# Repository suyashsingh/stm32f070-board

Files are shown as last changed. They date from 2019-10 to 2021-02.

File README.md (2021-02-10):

# Hardware Board Design for STM32F070F6
`STM32F070F6` is a 32-bit ARM Cortex-M0 microcontroller from ST. This repository contains the hardware files needed for creating a basic board for working with this micro controller. 

EDA Tool: **KiCad(5.0.1)**.

**Many thanks to [Balram](https://www.linkedin.com/in/balram-jatav/) for helping me out with the PCB design :slightly_smiling_face:**

## Images 
1. Real Board - before assembly
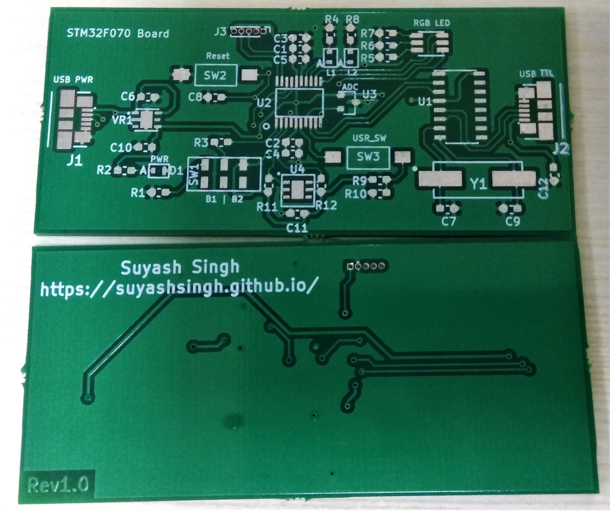
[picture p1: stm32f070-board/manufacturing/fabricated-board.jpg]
board-fab


2. 3D View of the Board
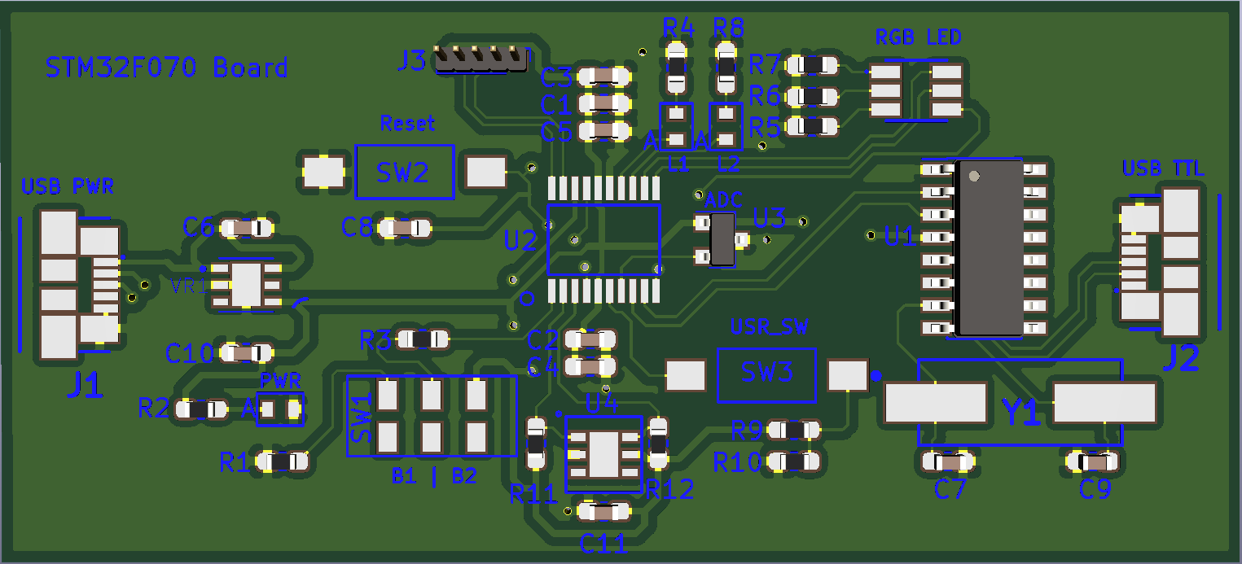
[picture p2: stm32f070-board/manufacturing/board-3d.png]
board-3d


3. Fab House Front Copper Layer
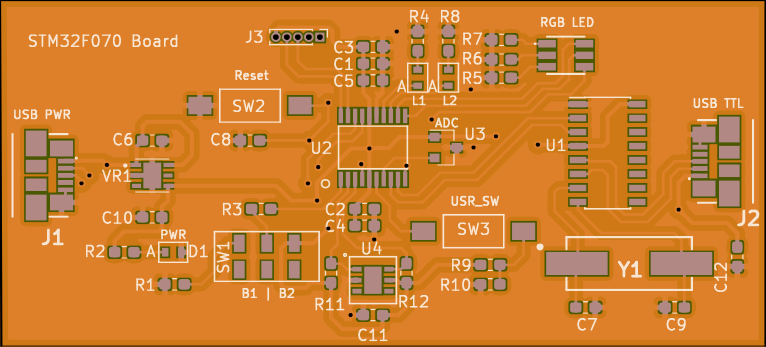
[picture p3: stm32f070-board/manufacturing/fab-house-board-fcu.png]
board-fcu


4. Board Front Copper Layer
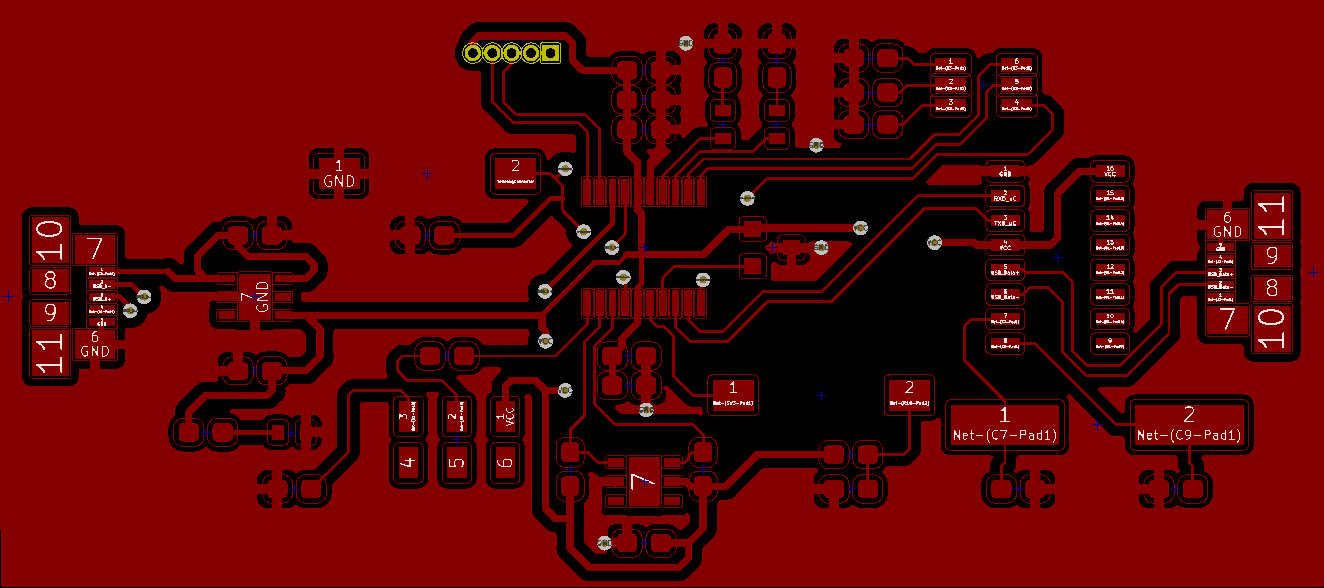
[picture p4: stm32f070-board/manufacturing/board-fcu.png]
board-fcu


## Board Bring Up Checklist
- [x] 1. Change trace width of power tracks
- [x] 2. Merge `dev` branch to master
- [x] 3. Export gerbers - research about fab houses
- [x] 4. Verify gerbers
- [x] 5. Send board to fab house
- [x] 6. Generate BOM
- [x] 7. Order component and tools

## Timeline
| Event | Date |
| --- | --- |
| Project Start | 12 Sep 2019 |
| Schematic Complete | 5th Oct 2019  |
| Layout Complete | 6th Oct 2019  |
| Sent gerbers for fabrication  | 3rd Dec 2019  |
| Received PCB's from fab house | 11th Dec 2019 |
| BOM Complete | 17th Dec 2019 |
| Ordered Components & Tools | 17th Dec 2019 |

## Notes
1. Changed the switches with were earlier decided from *robu.in* to [this](https://in.element14.com/alcoswitch-te-connectivity/fsmsm/switch-spst-0-05a-24vdc-smd/dp/1703878) from element14, as mechanical dimensions were not available.

2. Links that might be useful for usb connector:
	+ [Element 14 Page](https://in.element14.com/molex/47346-0001/usb-conn-2-0-micro-usb-type-b/dp/1568026?st=mirco%20usb%20connector)
	+ [Digi Key Kicad Library](https://github.com/Digi-Key/digikey-kicad-library/tree/master/) - Search for MPN
	+ [Mouser](https://www.mouser.in/ProductDetail/Molex/47346-0001?qs=c2CV6XM0DweJBWaSeyWeCw%3D%3D)

3. Always do a board check when you receive the board from the fab house. You can do:
	
	a. Visual Inspection
	
	b. Check for short between the power rails - This board has 3V3 and 5V power rails. Thanks to Balram for pointing out this.

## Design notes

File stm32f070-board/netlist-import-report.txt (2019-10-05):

Info: Checking netlist symbol footprint “R2:/5D7A0C0E:Resistor_SMD:R_0603_1608Metric_Pad1.05x0.95mm_HandSolder”.

Info: Checking netlist symbol footprint “C9:/5D8B533C:Capacitor_SMD:C_0603_1608Metric_Pad1.05x0.95mm_HandSolder”.

Info: Checking netlist symbol footprint “U3:/5D8108A1:Package_TO_SOT_SMD:SOT-23”.

Info: Checking netlist symbol footprint “C10:/5D7A0CB9:Capacitor_SMD:C_0603_1608Metric_Pad1.05x0.95mm_HandSolder”.

Info: Checking netlist symbol footprint “C11:/5D8253F2:Capacitor_SMD:C_0603_1608Metric_Pad1.05x0.95mm_HandSolder”.

Info: Checking netlist symbol footprint “D1:/5D7A0C7B:stm32f070-board:LED_VISHAY”.

Info: Checking netlist symbol footprint “D2:/5D7DA43F:stm32f070-board:LED_VISHAY”.

Info: Checking netlist symbol footprint “D3:/5D801829:stm32f070-board:PLCC6”.

Info: Checking netlist symbol footprint “U2:/5D7A7448:stm32f070-board:TSSOP20_P0.65mm”.

Info: Checking netlist symbol footprint “J1:/5D7A0AEB:stm32f070-board:usb”.

Info: Checking netlist symbol footprint “J2:/5D8A34F0:stm32f070-board:usb”.

Info: Checking netlist symbol footprint “J3:/5D7FD58A:Connector_PinHeader_1.00mm:PinHeader_1x05_P1.00mm_Vertical”.

Info: Checking netlist symbol footprint “U1:/5D88F99C:Package_SO:SOIC-16_3.9x9.9mm_P1.27mm”.

Info: Checking netlist symbol footprint “SW3:/5D8E3013:stm32f070-board:TACTILE_SWITCH_3.5X6.0mm”.

Info: Checking netlist symbol footprint “R1:/5D7D0CB6:Resistor_SMD:R_0603_1608Metric_Pad1.05x0.95mm_HandSolder”.

Info: Checking netlist symbol footprint “D4:/5D7D3C44:stm32f070-board:LED_VISHAY”.

Info: Checking netlist symbol footprint “SW2:/5D7AAB22:stm32f070-board:TACTILE_SWITCH_3.5X6.0mm”.

Info: Checking netlist symbol footprint “R3:/5D7A777D:Resistor_SMD:R_0603_1608Metric_Pad1.05x0.95mm_HandSolder”.

Info: Checking netlist symbol footprint “SW1:/5D7BECF9:stm32f070-board:SLIDE_SWITCH_3.6x9.0mm”.

Info: Checking netlist symbol footprint “R4:/5D7E3D28:Resistor_SMD:R_0603_1608Metric_Pad1.05x0.95mm_HandSolder”.

Info: Checking netlist symbol footprint “R5:/5D7D84F8:Resistor_SMD:R_0603_1608Metric_Pad1.05x0.95mm_HandSolder”.

Info: Checking netlist symbol footprint “R12:/5D82F9A1:Resistor_SMD:R_0603_1608Metric_Pad1.05x0.95mm_HandSolder”.

Info: Checking netlist symbol footprint “C1:/5D7AE4EA:Capacitor_SMD:C_0603_1608Metric_Pad1.05x0.95mm_HandSolder”.

Info: Checking netlist symbol footprint “R6:/5D7D84B2:Resistor_SMD:R_0603_1608Metric_Pad1.05x0.95mm_HandSolder”.

Info: Checking netlist symbol footprint “R11:/5D82FB6B:Resistor_SMD:R_0603_1608Metric_Pad1.05x0.95mm_HandSolder”.

Info: Checking netlist symbol footprint “R7:/5D7D845C:Resistor_SMD:R_0603_1608Metric_Pad1.05x0.95mm_HandSolder”.

Info: Checking netlist symbol footprint “R8:/5D7D3F06:Resistor_SMD:R_0603_1608Metric_Pad1.05x0.95mm_HandSolder”.

Info: Checking netlist symbol footprint “R10:/5D7B88B1:Resistor_SMD:R_0603_1608Metric_Pad1.05x0.95mm_HandSolder”.

Info: Checking netlist symbol footprint “R9:/5D7CB083:Resistor_SMD:R_0603_1608Metric_Pad1.05x0.95mm_HandSolder”.

Info: Checking netlist symbol footprint “C4:/5D7B4E86:Capacitor_SMD:C_0603_1608Metric_Pad1.05x0.95mm_HandSolder”.

Info: Checking netlist symbol footprint “VR1:/5D7A09D8:stm32f070-board:voltage-reg”.

Info: Checking netlist symbol footprint “C7:/5D8B4EE6:Capacitor_SMD:C_0603_1608Metric_Pad1.05x0.95mm_HandSolder”.

Info: Checking netlist symbol footprint “C5:/5D7AE616:Capacitor_SMD:C_0603_1608Metric_Pad1.05x0.95mm_HandSolder”.

Info: Checking netlist symbol footprint “C6:/5D7A0BBE:Capacitor_SMD:C_0603_1608Metric_Pad1.05x0.95mm_HandSolder”.

Info: Checking netlist symbol footprint “Y1:/5D8B4C70:stm32f070-board:HC_49US-(AT49)_1”.

Info: Checking netlist symbol footprint “C2:/5D7B4ED0:Capacitor_SMD:C_0603_1608Metric_Pad1.05x0.95mm_HandSolder”.

Info: Checking netlist symbol footprint “C3:/5D7AE5E0:Capacitor_SMD:C_0603_1608Metric_Pad1.05x0.95mm_HandSolder”.

Info: Checking netlist symbol footprint “U4:/5D81A91E:stm32f070-board:Si705x_Footprint_P1.0mm”.

Info: Checking netlist symbol footprint “C8:/5D7AACAA:Capacitor_SMD:C_0603_1608Metric_Pad1.05x0.95mm_HandSolder”.

Adding new symbol “SW2:/5D7AAB22” footprint “stm32f070-board:TACTILE_SWITCH_3.5X6.0mm”.

Changing footprint “SW2:/5D7AAB22” pad “2” net name from “” to “/ToDebugConnector”.

Adding new symbol “VR1:/5D7A09D8” footprint “stm32f070-board:voltage-reg”.

Changing footprint “VR1:/5D7A09D8” pad “7” net name from “” to “GND”.

Changing footprint “SW1:/5D7BECF9” pad “3” net name from “” to “Net-(R1-Pad2)”.

Changing footprint “SW1:/5D7BECF9” pad “2” net name from “” to “Net-(R3-Pad2)”.

Adding new symbol “SW3:/5D8E3013” footprint “stm32f070-board:TACTILE_SWITCH_3.5X6.0mm”.

Changing footprint “SW2:/5D7AAB22” pad “1” net name from “” to “GND”.

Changing footprint “VR1:/5D7A09D8” pad “4” net name from “” to “VCC”.

Changing footprint “SW3:/5D8E3013” pad “1” net name from “” to “Net-(SW3-Pad1)”.

Changing footprint “SW3:/5D8E3013” pad “2” net name from “” to “Net-(R10-Pad2)”.

Changing footprint “U4:/5D81A91E” pad “6” net name from “” to “/SCL”.

Adding new symbol “U1:/5D88F99C” footprint “Package_SO:SOIC-16_3.9x9.9mm_P1.27mm”.

Changing footprint “U4:/5D81A91E” pad “5” net name from “” to “VCC”.

Changing footprint “U1:/5D88F99C” pad “1” net name from “” to “GND”.

Changing footprint “U1:/5D88F99C” pad “2” net name from “” to “/RXD_uC”.

Changing footprint “U1:/5D88F99C” pad “3” net name from “” to “/TXD_uC”.

Changing footprint “VR1:/5D7A09D8” pad “1” net name from “” to “Net-(C6-Pad1)”.

Changing footprint “Y1:/5D8B4C70” pad “2” net name from “” to “Net-(C9-Pad1)”.

Changing footprint “R9:/5D7CB083” pad “2” net name from “” to “VCC”.

Changing footprint “R9:/5D7CB083” pad “1” net name from “” to “Net-(R10-Pad2)”.

Changing footprint “Y1:/5D8B4C70” pad “1” net name from “” to “Net-(C7-Pad1)”.

Adding new symbol “Y1:/5D8B4C70” footprint “stm32f070-board:HC_49US-(AT49)_1”.

Adding new symbol “R10:/5D7B88B1” footprint “Resistor_SMD:R_0603_1608Metric_Pad1.05x0.95mm_HandSolder”.

Changing footprint “R10:/5D7B88B1” pad “1” net name from “” to “GND”.

Changing footprint “R10:/5D7B88B1” pad “2” net name from “” to “Net-(R10-Pad2)”.

Adding new symbol “R11:/5D82FB6B” footprint “Resistor_SMD:R_0603_1608Metric_Pad1.05x0.95mm_HandSolder”.

Changing footprint “R11:/5D82FB6B” pad “2” net name from “” to “/SDA”.

Changing footprint “SW1:/5D7BECF9” pad “1” net name from “” to “VCC”.

Changing footprint “VR1:/5D7A09D8” pad “2” net name from “” to “GND”.

Changing footprint “R11:/5D82FB6B” pad “1” net name from “” to “VCC”.

Changing footprint “VR1:/5D7A09D8” pad “3” net name from “” to “Net-(VR1-Pad3)”.

Adding new symbol “R12:/5D82F9A1” footprint “Resistor_SMD:R_0603_1608Metric_Pad1.05x0.95mm_HandSolder”.

Changing footprint “R12:/5D82F9A1” pad “1” net name from “” to “VCC”.

Changing footprint “R12:/5D82F9A1” pad “2” net name from “” to “/SCL”.

Changing footprint “U1:/5D88F99C” pad “6” net name from “” to “Net-(J2-Pad2)”.

Changing footprint “VR1:/5D7A09D8” pad “6” net name from “” to “Net-(C6-Pad1)”.

Adding new symbol “SW1:/5D7BECF9” footprint “stm32f070-board:SLIDE_SWITCH_3.6x9.0mm”.

Changing footprint “U2:/5D7A7448” pad “17” net name from “” to “/USB_DM”.

Changing footprint “U2:/5D7A7448” pad “6” net name from “” to “Net-(SW3-Pad1)”.

Changing footprint “U4:/5D81A91E” pad “2” net name from “” to “GND”.

Changing footprint “U2:/5D7A7448” pad “7” net name from “” to “/ADC”.

Changing footprint “U2:/5D7A7448” pad “8” net name from “” to “/TXD_uC”.

Changing footprint “U2:/5D7A7448” pad “9” net name from “” to “/RXD_uC”.

Changing footprint “U4:/5D81A91E” pad “1” net name from “” to “/SDA”.

Changing footprint “U2:/5D7A7448” pad “10” net name from “” to “Net-(D3-Pad4)”.

Changing footprint “U2:/5D7A7448” pad “20” net name from “” to “/PA20”.

Changing footprint “U2:/5D7A7448” pad “19” net name from “” to “/PA19”.

Changing footprint “U2:/5D7A7448” pad “18” net name from “” to “/USB_DP”.

Changing footprint “U2:/5D7A7448” pad “5” net name from “” to “VCC”.

Changing footprint “U2:/5D7A7448” pad “16” net name from “” to “VCC”.

Adding new symbol “U4:/5D81A91E” footprint “stm32f070-board:Si705x_Footprint_P1.0mm”.

Changing footprint “U2:/5D7A7448” pad “15” net name from “” to “GND”.

Changing footprint “U2:/5D7A7448” pad “14” net name from “” to “Net-(D2-Pad2)”.

Changing footprint “U2:/5D7A7448” pad “13” net name from “” to “Net-(D4-Pad2)”.

Changing footprint “U2:/5D7A7448” pad “12” net name from “” to “Net-(D3-Pad6)”.

Changing footprint “U2:/5D7A7448” pad “11” net name from “” to “Net-(D3-Pad5)”.

Changing footprint “U3:/5D8108A1” pad “3” net name from “” to “GND”.

Adding new symbol “U3:/5D8108A1” footprint “Package_TO_SOT_SMD:SOT-23”.

Changing footprint “U3:/5D8108A1” pad “1” net name from “” to “VCC”.

Changing footprint “U1:/5D88F99C” pad “14” net name from “” to “Net-(U1-Pad14)”.

Changing footprint “U1:/5D88F99C” pad “5” net name from “” to “Net-(J2-Pad3)”.

Changing footprint “U3:/5D8108A1” pad “2” net name from “” to “/ADC”.

Changing footprint “U1:/5D88F99C” pad “7” net name from “” to “Net-(C7-Pad1)”.

Changing footprint “U4:/5D81A91E” pad “4” net name from “” to “Net-(U4-Pad4)”.

Changing footprint “U1:/5D88F99C” pad “8” net name from “” to “Net-(C9-Pad1)”.

Changing footprint “U1:/5D88F99C” pad “9” net name from “” to “Net-(U1-Pad9)”.

Changing footprint “U1:/5D88F99C” pad “10” net name from “” to “Net-(U1-Pad10)”.

Changing footprint “U1:/5D88F99C” pad “11” net name from “” to “Net-(U1-Pad11)”.

Changing footprint “U1:/5D88F99C” pad “12” net name from “” to “Net-(U1-Pad12)”.

Changing footprint “U1:/5D88F99C” pad “13” net name from “” to “Net-(U1-Pad13)”.

Changing footprint “U1:/5D88F99C” pad “4” net name from “” to “VCC”.

Changing footprint “U1:/5D88F99C” pad “15” net name from “” to “Net-(U1-Pad15)”.

Changing footprint “U1:/5D88F99C” pad “16” net name from “” to “VCC”.

Changing footprint “U4:/5D81A91E” pad “3” net name from “” to “Net-(U4-Pad3)”.

Changing footprint “R5:/5D7D84F8” pad “1” net name from “” to “Net-(D3-Pad3)”.

Adding new symbol “U2:/5D7A7448” footprint “stm32f070-board:TSSOP20_P0.65mm”.

Changing footprint “U2:/5D7A7448” pad “1” net name from “” to “Net-(R3-Pad1)”.

Changing footprint “U2:/5D7A7448” pad “2” net name from “” to “/SDA”.

Changing footprint “U2:/5D7A7448” pad “3” net name from “” to “/SCL”.

Changing footprint “U2:/5D7A7448” pad “4” net name from “” to “/ToDebugConnector”.

Changing footprint “D1:/5D7A0C7B” pad “2” net name from “” to “Net-(D1-Pad2)”.

Changing footprint “C8:/5D7AACAA” pad “1” net name from “” to “/ToDebugConnector”.

Adding new symbol “C9:/5D8B533C” footprint “Capacitor_SMD:C_0603_1608Metric_Pad1.05x0.95mm_HandSolder”.

Changing footprint “C9:/5D8B533C” pad “1” net name from “” to “Net-(C9-Pad1)”.

Changing footprint “C9:/5D8B533C” pad “2” net name from “” to “GND”.

Adding new symbol “C10:/5D7A0CB9” footprint “Capacitor_SMD:C_0603_1608Metric_Pad1.05x0.95mm_HandSolder”.

Changing footprint “C10:/5D7A0CB9” pad “2” net name from “” to “GND”.

Changing footprint “C10:/5D7A0CB9” pad “1” net name from “” to “VCC”.

Adding new symbol “C11:/5D8253F2” footprint “Capacitor_SMD:C_0603_1608Metric_Pad1.05x0.95mm_HandSolder”.

Changing footprint “C11:/5D8253F2” pad “1” net name from “” to “GND”.

Changing footprint “C11:/5D8253F2” pad “2” net name from “” to “VCC”.

Adding new symbol “D1:/5D7A0C7B” footprint “stm32f070-board:LED_VISHAY”.

Changing footprint “C8:/5D7AACAA” pad “2” net name from “” to “GND”.

Changing footprint “D1:/5D7A0C7B” pad “1” net name from “” to “GND”.

Adding new symbol “D2:/5D7DA43F” footprint “stm32f070-board:LED_VISHAY”.

Changing footprint “D2:/5D7DA43F” pad “1” net name from “” to “Net-(D2-Pad1)”.

Changing footprint “D2:/5D7DA43F” pad “2” net name from “” to “Net-(D2-Pad2)”.

Adding new symbol “D3:/5D801829” footprint “stm32f070-board:PLCC6”.

Changing footprint “D3:/5D801829” pad “1” net name from “” to “Net-(D3-Pad1)”.

Changing footprint “D3:/5D801829” pad “2” net name from “” to “Net-(D3-Pad2)”.

Changing footprint “D3:/5D801829” pad “3” net name from “” to “Net-(D3-Pad3)”.

Changing footprint “D3:/5D801829” pad “4” net name from “” to “Net-(D3-Pad4)”.

Changing footprint “D3:/5D801829” pad “5” net name from “” to “Net-(D3-Pad5)”.

Changing footprint “D3:/5D801829” pad “6” net name from “” to “Net-(D3-Pad6)”.

Changing footprint “C4:/5D7B4E86” pad “1” net name from “” to “VCC”.

Adding new symbol “C1:/5D7AE4EA” footprint “Capacitor_SMD:C_0603_1608Metric_Pad1.05x0.95mm_HandSolder”.

Changing footprint “C1:/5D7AE4EA” pad “1” net name from “” to “VCC”.

Changing footprint “C1:/5D7AE4EA” pad “2” net name from “” to “GND”.

Adding new symbol “C2:/5D7B4ED0” footprint “Capacitor_SMD:C_0603_1608Metric_Pad1.05x0.95mm_HandSolder”.

Changing footprint “C2:/5D7B4ED0” pad “1” net name from “” to “VCC”.

Changing footprint “C2:/5D7B4ED0” pad “2” net name from “” to “GND”.

Adding new symbol “C3:/5D7AE5E0” footprint “Capacitor_SMD:C_0603_1608Metric_Pad1.05x0.95mm_HandSolder”.

Changing footprint “C3:/5D7AE5E0” pad “2” net name from “” to “GND”.

Changing footprint “C3:/5D7AE5E0” pad “1” net name from “” to “VCC”.

Adding new symbol “C4:/5D7B4E86” footprint “Capacitor_SMD:C_0603_1608Metric_Pad1.05x0.95mm_HandSolder”.

Changing footprint “C4:/5D7B4E86” pad “2” net name from “” to “GND”.

Adding new symbol “D4:/5D7D3C44” footprint “stm32f070-board:LED_VISHAY”.

Adding new symbol “C5:/5D7AE616” footprint “Capacitor_SMD:C_0603_1608Metric_Pad1.05x0.95mm_HandSolder”.

Changing footprint “C5:/5D7AE616” pad “1” net name from “” to “VCC”.

Changing footprint “C5:/5D7AE616” pad “2” net name from “” to “GND”.

Adding new symbol “C6:/5D7A0BBE” footprint “Capacitor_SMD:C_0603_1608Metric_Pad1.05x0.95mm_HandSolder”.

Changing footprint “C6:/5D7A0BBE” pad “1” net name from “” to “Net-(C6-Pad1)”.

Changing footprint “C6:/5D7A0BBE” pad “2” net name from “” to “GND”.

Adding new symbol “C7:/5D8B4EE6” footprint “Capacitor_SMD:C_0603_1608Metric_Pad1.05x0.95mm_HandSolder”.

Changing footprint “C7:/5D8B4EE6” pad “2” net name from “” to “GND”.

Changing footprint “C7:/5D8B4EE6” pad “1” net name from “” to “Net-(C7-Pad1)”.

Adding new symbol “C8:/5D7AACAA” footprint “Capacitor_SMD:C_0603_1608Metric_Pad1.05x0.95mm_HandSolder”.

Adding new symbol “R5:/5D7D84F8” footprint “Resistor_SMD:R_0603_1608Metric_Pad1.05x0.95mm_HandSolder”.

Changing footprint “R1:/5D7D0CB6” pad “2” net name from “” to “Net-(R1-Pad2)”.

Changing footprint “R1:/5D7D0CB6” pad “1” net name from “” to “GND”.

Adding new symbol “R2:/5D7A0C0E” footprint “Resistor_SMD:R_0603_1608Metric_Pad1.05x0.95mm_HandSolder”.

Changing footprint “R2:/5D7A0C0E” pad “1” net name from “” to “VCC”.

Changing footprint “R2:/5D7A0C0E” pad “2” net name from “” to “Net-(D1-Pad2)”.

Adding new symbol “R3:/5D7A777D” footprint “Resistor_SMD:R_0603_1608Metric_Pad1.05x0.95mm_HandSolder”.

Changing footprint “R3:/5D7A777D” pad “2” net name from “” to “Net-(R3-Pad2)”.

Changing footprint “R3:/5D7A777D” pad “1” net name from “” to “Net-(R3-Pad1)”.

Adding new symbol “R4:/5D7E3D28” footprint “Resistor_SMD:R_0603_1608Metric_Pad1.05x0.95mm_HandSolder”.

Changing footprint “R4:/5D7E3D28” pad “1” net name from “” to “Net-(D2-Pad1)”.

Changing footprint “R4:/5D7E3D28” pad “2” net name from “” to “GND”.

Adding new symbol “R1:/5D7D0CB6” footprint “Resistor_SMD:R_0603_1608Metric_Pad1.05x0.95mm_HandSolder”.

Changing footprint “R5:/5D7D84F8” pad “2” net name from “” to “GND”.

Adding new symbol “R6:/5D7D84B2” footprint “Resistor_SMD:R_0603_1608Metric_Pad1.05x0.95mm_HandSolder”.

Changing footprint “R6:/5D7D84B2” pad “1” net name from “” to “Net-(D3-Pad2)”.

Changing footprint “R6:/5D7D84B2” pad “2” net name from “” to “GND”.

Adding new symbol “R7:/5D7D845C” footprint “Resistor_SMD:R_0603_1608Metric_Pad1.05x0.95mm_HandSolder”.

Changing footprint “R7:/5D7D845C” pad “2” net name from “” to “GND”.

Changing footprint “R7:/5D7D845C” pad “1” net name from “” to “Net-(D3-Pad1)”.

Adding new symbol “R8:/5D7D3F06” footprint “Resistor_SMD:R_0603_1608Metric_Pad1.05x0.95mm_HandSolder”.

Changing footprint “R8:/5D7D3F06” pad “1” net name from “” to “Net-(D4-Pad1)”.

Changing footprint “R8:/5D7D3F06” pad “2” net name from “” to “GND”.

Changing footprint “J2:/5D8A34F0” pad “5” net name from “” to “GND”.

Changing footprint “D4:/5D7D3C44” pad “2” net name from “” to “Net-(D4-Pad2)”.

Changing footprint “D4:/5D7D3C44” pad “1” net name from “” to “Net-(D4-Pad1)”.

Adding new symbol “J1:/5D7A0AEB” footprint “stm32f070-board:usb”.

Changing footprint “J1:/5D7A0AEB” pad “1” net name from “” to “Net-(C6-Pad1)”.

Changing footprint “J1:/5D7A0AEB” pad “2” net name from “” to “/USB_DM”.

Changing footprint “J1:/5D7A0AEB” pad “3” net name from “” to “/USB_DP”.

Changing footprint “J1:/5D7A0AEB” pad “4” net name from “” to “Net-(J1-Pad4)”.

Changing footprint “J1:/5D7A0AEB” pad “5” net name from “” to “GND”.

Changing footprint “J1:/5D7A0AEB” pad “6” net name from “” to “GND”.

Adding new symbol “J2:/5D8A34F0” footprint “stm32f070-board:usb”.

Changing footprint “J2:/5D8A34F0” pad “6” net name from “” to “GND”.

Adding new symbol “R9:/5D7CB083” footprint “Resistor_SMD:R_0603_1608Metric_Pad1.05x0.95mm_HandSolder”.

Changing footprint “J2:/5D8A34F0” pad “4” net name from “” to “Net-(J2-Pad4)”.

Changing footprint “J2:/5D8A34F0” pad “3” net name from “” to “Net-(J2-Pad3)”.

Changing footprint “J2:/5D8A34F0” pad “2” net name from “” to “Net-(J2-Pad2)”.

Changing footprint “J2:/5D8A34F0” pad “1” net name from “” to “Net-(J2-Pad1)”.

Adding new symbol “J3:/5D7FD58A” footprint “Connector_PinHeader_1.00mm:PinHeader_1x05_P1.00mm_Vertical”.

Changing footprint “J3:/5D7FD58A” pad “1” net name from “” to “/ToDebugConnector”.

Changing footprint “J3:/5D7FD58A” pad “2” net name from “” to “GND”.

Changing footprint “J3:/5D7FD58A” pad “3” net name from “” to “/PA19”.

Changing footprint “J3:/5D7FD58A” pad “4” net name from “” to “/PA20”.

Changing footprint “J3:/5D7FD58A” pad “5” net name from “” to “VCC”.

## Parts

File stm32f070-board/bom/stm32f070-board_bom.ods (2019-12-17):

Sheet: Components
Component | Description | Part | References | Value | Footprint | MPM | Manufacturer | Quantity Per PCB | Build Quantity(for 3 Boards) | Unit Price | Min Order Qty | Order Qty | Total Price | Vendor Page | Remarks | Source
1 | Unpolarized capacitor | C | C3 C5 C11 | 100nF | C_0603_1608Metric_Pad1.05x0.95mm_HandSolder | MC0603B104M160CT | MULTICOMP PRO | 3 | 9 | 0.978 | 1 |  | 0 | https://in.element14.com/multicomp/mc0603b104m160ct/ceramic-capacitor-0-1uf-16v-x7r/dp/1709956 | 16V | Buy locally
2 | Unpolarized capacitor | C | C8 | 100uF | C_0603_1608Metric_Pad1.05x0.95mm_HandSolder |  |  | 1 | 3 |  |  |  | 0 |  | Use 4.7uF if you don't find 100uF in local market | Buy Localy
3 | Unpolarized capacitor | C | C2 | 10nF | C_0603_1608Metric_Pad1.05x0.95mm_HandSolder | MC0603B103M500CT | MULTICOMP PRO | 1 | 3 | 0.734 | 1 |  | 0 | https://in.element14.com/multicomp/mc0603b103m500ct/ceramic-capacitor-0-01uf-50v-x7r/dp/1709948 | 50V | Buy locally
4 | Unpolarized capacitor | C | C4 C6 C10 C12 | 1uF | C_0603_1608Metric_Pad1.05x0.95mm_HandSolder | MC0603X105K100CT | MULTICOMP PRO | 4 | 12 |  |  |  | 0 | https://in.element14.com/multicomp/mc0603x105k100ct/cap-1-f-10v-10-x5r-0603/dp/1759399RL | NO longer Manufactured | Buy locally
5 | Unpolarized capacitor | C | C7 C9 | 22pF | C_0603_1608Metric_Pad1.05x0.95mm_HandSolder | 0603N220J500CT | WALSIN | 2 | 6 | 2.04 | 10 |  | 0 | https://in.element14.com/walsin/0603n220j500ct/cap-22pf-50v-5-c0g-np0-0603/dp/2496893 | 50V | Buy locally
6 | Unpolarized capacitor | C | C1 | 4.7uF | C_0603_1608Metric_Pad1.05x0.95mm_HandSolder | 0603F475Z100CT | WALSIN | 1 | 3 | 13.64 | 10 |  | 0 | https://in.element14.com/walsin/0603f475z100ct/cap-4-7-f-10v-y5v-0603-reel/dp/2524873 | 10V – You will have to buy extra for C8 | Buy locally
7 | RGB Led | LED_RGB | D3 | LED_RGB | PLCC6 | CLX6F-FKC-CNP1ST1E1BB7D3D3 | CREE | 1 | 3 | 23.14 | 1 | 3 | 69.42 | https://in.element14.com/cree/clx6f-fkc-cnp1st1e1bb7d3d3/led-aec-q101-rgb-750-1350-240mcd/dp/2840590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 | ok | Element14
8 | Light emitting diode | LED | D1 | PWR_LED | LED_VISHAY | TLMS1000-GS08 | Vishay | 1 | 3 | 30.17 | 1 | 3 | 90.51 | https://in.element14.com/vishay/tlms1000-gs08/led-0603-red-4mcd-628nm/dp/1328308 | ok
9 | Light emitting diode | LED | D4 | USR_LED1 | LED_VISHAY | TLMS1000-GS08 | Vishay | 1 | 3 | 30.37 | 1 | 0 | 0 | https://in.element14.com/vishay/tlms1000-gs08/led-0603-red-4mcd-628nm/dp/1328308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 | ok
10 | Light emitting diode | LED | D2 | USR_LED2 | LED_VISHAY | TLMS1000-GS08 | Vishay | 1 | 3 | 30.37 | 1 | 0 | 0 | https://in.element14.com/vishay/tlms1000-gs08/led-0603-red-4mcd-628nm/dp/1328308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 | ok
11 | Generic connector, single row, 01x05 | Conn_01x05_Male | J3 | Conn_01x05_Male | PinHeader_1x05_P1.00mm_Vertical | M52-040023V0545 | Harvin | 1 | 3 | 58.42 | 1 |  | 0 | https://in.element14.com/harwin/m52-040023v0545/header-tht-vertical-1-27mm-5way/dp/1099560 | ok | Buy locally
12 | USB Micro Type B connector | USB_B_Micro | J1 J2 | USB_B_Micro | usb | 47346-0001 | Molex | 2 | 6 | 66.26 | 1 | 4 | 265.04 | https://in.element14.com/molex/47346-0001/usb-conn-2-0-micro-usb-type-b/dp/1568026?st=mirco usb connector | ok | Element14
13 | Resistor | R | R1 R10 | 0R | R_0603_1608Metric_Pad1.05x0.95mm_HandSolder | WR06X000 PTL | WALSIN | 2 | 6 | 0.56 | 10 | 20 | 11.2 | https://in.element14.com/walsin/wr06x000-ptl/res-0r0-0603-thick-film/dp/2502392RL | ok | Buy locally
14 | Resistor | R | R3 R9 R11 R12 | 10k | R_0603_1608Metric_Pad1.05x0.95mm_HandSolder | WR06X1002FTL | WALSIN | 4 | 12 | 0.693 | 10 | 10 | 6.93 | https://in.element14.com/walsin/wr06x1002ftl/res-10k-1-75v-0603-thick-film/dp/2502397 | ok | Buy locally
15 | Resistor | R | R7 | 30R | R_0603_1608Metric_Pad1.05x0.95mm_HandSolder | WR06X30R0FTL | WALSIN | 1 | 3 | 0.693 | 10 | 10 | 6.93 | https://in.element14.com/walsin/wr06x30r0ftl/res-30r-1-0-1w-0603-thick-film/dp/2670750 | ok | Buy locally
16 | Resistor | R | R6 | 60R | R_0603_1608Metric_Pad1.05x0.95mm_HandSolder | MCWR06X62R0FTL | MULTICOMP PRO | 1 | 3 | 0.28 | 10 | 10 | 2.8 | https://in.element14.com/multicomp/mcwr06x62r0ftl/res-62r-1-0-1w-thick-film/dp/2447415 | ok | Buy locally
17 | Resistor | R | R2 R4 R8 | 750R | R_0603_1608Metric_Pad1.05x0.95mm_HandSolder | MCWR06X7500FTL | MULTICOMP PRO | 3 | 9 | 0.29 | 10 | 10 | 2.9 | https://in.element14.com/multicomp/mcwr06x7500ftl/res-750r-1-0-1w-thick-film/dp/2447432 | ok | Buy locally
18 | Resistor | R | R5 | 80R | R_0603_1608Metric_Pad1.05x0.95mm_HandSolder |  |  | 1 | 3 | 0.27 | 10 | 10 | 2.7 | https://in.element14.com/multicomp/mcwr06x82r0ftl/res-82r-1-0-1w-thick-film/dp/2447439 | ok | Buy locally
19 | Switch, dual pole double throw | SW_DPDT_x2 | SW1 | SW_DPDT_x2 | SLIDE_SWITCH_3.6x9.0mm |  |  | 1 | 3 | 35.22 | 1 | 2 | 70.44 | https://in.element14.com/c-k-components/js202011jcqn/slide-switch-dpdt-0-3a-6vdc-smd/dp/2931766 | ok | Element14
20 | Push button switch, generic, two pins | SW_Push | SW2 SW3 | SW_Push | TACTILE_SWITCH_3.5X6.0mm | FSMSM | ALCOSWITCH - TE CONNECTIVITY | 2 | 6 | 22.21 | 1 | 4 | 88.84 | https://in.element14.com/alcoswitch-te-connectivity/fsmsm/switch-spst-0-05a-24vdc-smd/dp/1703878 | ok | Element14
21 | USB serial converter, UART, SOIC-16 | CH340G | U1 | CH340G | SOIC-16_3.9x9.9mm_P1.27mm | Local |  | 1 | 3 | 43 | 1 | 2 | 86 | https://robu.in/product/ch340g-soic16-usb-to-serial-ttl-rs232-converter-ic/ | Locally purchased
22 | Low power, analog thermistor temperature sensor,SOT-23-3 | MCP9700AT-ETT | U3 | MCP9700AT-ETT | SOT-23 | MCP9700AT-E/TT | MICROCHIP | 1 | 3 | 22.64 | 1 | 2 | 45.28 | https://in.element14.com/microchip/mcp9700at-e-tt/sensor-temperature-1deg-c-3sot23/dp/1605577 | ok | Element14
23 | STM Microcontroller | STM32F070F6P6 | U2 | STM32F070F6P6 | TSSOP20_P0.65mm | STM32F070F6P6TR | STMICROELECTRONICS | 1 | 3 | 103.4 | 1 | 2 | 206.8 | https://in.element14.com/stmicroelectronics/stm32f070f6p6tr/mcu-32bit-48mhz-tssop-20/dp/3129808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 | ok | Element14
24 | I2C Temperature Sensor, DFN-6 | Si7055-A20 | U4 | Si7055-A20 | Si705x_Footprint_P1.0mm | SI7055-A20-IMR | SILICON LABS | 1 | 3 | 106.83 | 1 | 1 | 106.83 | https://in.element14.com/silicon-labs/si7055-a20-imr/temp-sensor-i2c-output-dfn-6/dp/3105973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 | Backorder | Element14
25 | Linear Voltage Regulator | LD39050PU33R | VR1 | LD39050PU33R | voltage-reg | LD39050PU33R | STMICROELECTRONICS | 1 | 3 | 79.6 | 1 | 2 | 159.2 | https://in.element14.com/stmicroelectronics/ld39050pu33r/ldo-fixed-3-3v-0-5a-dfn-6/dp/2762703 | ok | Element14
26 | Two pin crystal | Crystal | Y1 | 12MHz | HC_49US-(AT49)_1 | ABLS-12.000MHZ-B4-T | ABRACON | 1 | 3 | 18.89 | 1 | 2 | 37.78 | https://in.element14.com/abracon/abls-12-000mhz-b4-t/crystal-12mhz-18pf-hc-49us/dp/2467716 | ok | Element14
 | Board Summary
Component Groups: | 26
Component Count: | 40
Fitted Components: | 40
Number of PCBs: | 3
Total components: | 120
Schematic Version: | v1.0
Schematic Date: | 2019-09-12
BoM Date: | 12/05/19 17:01:08
Schematic Source: | C:\Users\Suyash\Desktop\stm32f070-board\stm32f070-board\stm32f070-board.sch
KiCad Version: | Eeschema (5.0.1)-3

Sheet: Purchase
Component Purchase
Sl.No | Source
1 | Local Purchase
2 | Element 14 – Online
3 | Robu.in – Online
1. Local Purchase
Component |  | References | Value | Quantity Per PCB | Remarks
1 |  | C3 C5 C11 | 100nF | 3
2 |  | C8 | 100uF | 1 | Use 4.7uF if you don't find 100uF in local market
3 |  | C2 | 10nF | 1
4 |  | C4 C6 C10 C12 | 1uF | 4
5 |  | C7 C9 | 22pF | 2
6 |  | C1 | 4.7uF | 1
13 |  | R1 R10 | 0R | 2
14 |  | R3 R9 R11 R12 | 10k | 4
15 |  | R7 | 30R | 1
16 |  | R6 | 60R | 1
17 |  | R2 R4 R8 | 750R | 3
18 |  | R5 | 80R | 1
2. Element 14
Component |  | References | Value | Quantity Per PCB | Unit Price | Min Order Qty | Order Qty | Total Price | Vendor Page | Remarks | Source
7 |  | D3 | LED_RGB | 1 | 23.14 | 1 | 3 | 69.42 | https://in.element14.com/cree/clx6f-fkc-cnp1st1e1bb7d3d3/led-aec-q101-rgb-750-1350-240mcd/dp/2840590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 | ok | Element14
8 |  | D1 | PWR_LED | 1 | 30.17 | 1 | 3 | 90.51 | https://in.element14.com/vishay/tlms1000-gs08/led-0603-red-4mcd-628nm/dp/1328308 | ok | Element14
9 |  | D4 | USR_LED1 | 1 | 30.37 | 1 | 0 | 0 | https://in.element14.com/vishay/tlms1000-gs08/led-0603-red-4mcd-628nm/dp/1328308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 | ok | Element14
10 |  | D2 | USR_LED2 | 1 | 30.37 | 1 | 0 | 0 | https://in.element14.com/vishay/tlms1000-gs08/led-0603-red-4mcd-628nm/dp/1328308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 | ok | Element14
12 |  | J1 J2 | USB_B_Micro | 2 | 66.26 | 1 | 4 | 265.04 | https://in.element14.com/molex/47346-0001/usb-conn-2-0-micro-usb-type-b/dp/1568026?st=mirco usb connector | ok | Element14
13 |  | R1 R10 | 0R | 2 | 0.56 | 10 | 20 | 11.2 | https://in.element14.com/walsin/wr06x000-ptl/res-0r0-0603-thick-film/dp/2502392RL | 150 minimum quantity | Buy locally | https://in.element14.com/vishay/crcw06030000z0eahp/res-0r-0-25w-0603-thick-film/dp/2616740
14 |  | R3 R9 R11 R12 | 10k | 4 | 0.693 | 10 | 10 | 6.93 | https://in.element14.com/walsin/wr06x1002ftl/res-10k-1-75v-0603-thick-film/dp/2502397 | ok | Buy locally
15 |  | R7 | 30R | 1 | 0.693 | 10 | 10 | 6.93 | https://in.element14.com/walsin/wr06x30r0ftl/res-30r-1-0-1w-0603-thick-film/dp/2670750 | ok | Buy locally
16 |  | R6 | 60R | 1 | 0.28 | 10 | 10 | 2.8 | https://in.element14.com/multicomp/mcwr06x62r0ftl/res-62r-1-0-1w-thick-film/dp/2447415 | ok | Buy locally
17 |  | R2 R4 R8 | 750R | 3 | 0.29 | 10 | 10 | 2.9 | https://in.element14.com/multicomp/mcwr06x7500ftl/res-750r-1-0-1w-thick-film/dp/2447432 | ok | Buy locally
18 |  | R5 | 80R | 1 | 0.27 | 10 | 10 | 2.7 | https://in.element14.com/multicomp/mcwr06x82r0ftl/res-82r-1-0-1w-thick-film/dp/2447439 | ok | Buy locally
19 |  | SW1 | SW_DPDT_x2 | 1 | 35.22 | 1 | 2 | 70.44 | https://in.element14.com/c-k-components/js202011jcqn/slide-switch-dpdt-0-3a-6vdc-smd/dp/2931766 | ok | Element14
20 |  | SW2 SW3 | SW_Push | 2 | 22.21 | 1 | 4 | 88.84 | https://in.element14.com/alcoswitch-te-connectivity/fsmsm/switch-spst-0-05a-24vdc-smd/dp/1703878 | ok | Element14
22 |  | U3 | MCP9700AT-ETT | 1 | 22.64 | 1 | 2 | 45.28 | https://in.element14.com/microchip/mcp9700at-e-tt/sensor-temperature-1deg-c-3sot23/dp/1605577 | ok | Element14
23 |  | U2 | STM32F070F6P6 | 1 | 103.4 | 1 | 2 | 206.8 | https://in.element14.com/stmicroelectronics/stm32f070f6p6tr/mcu-32bit-48mhz-tssop-20/dp/3129808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 | ok | Element14
24 |  | U4 | Si7055-A20 | 1 | 106.83 | 1 | 1 | 106.83 | https://in.element14.com/silicon-labs/si7055-a20-imr/temp-sensor-i2c-output-dfn-6/dp/3105973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 | Backorder | Element14
25 |  | VR1 | LD39050PU33R | 1 | 79.6 | 1 | 2 | 159.2 | https://in.element14.com/stmicroelectronics/ld39050pu33r/ldo-fixed-3-3v-0-5a-dfn-6/dp/2762703 | ok | Element14
26 |  | Y1 | 12MHz | 1 | 18.89 | 1 | 2 | 37.78 | https://in.element14.com/abracon/abls-12-000mhz-b4-t/crystal-12mhz-18pf-hc-49us/dp/2467716 | ok | Element14
3. Robu.in
Component |  | References | Value | Quantity Per PCB | Unit Price | Min Order Qty | Order Qty | Total Price | Vendor Page | Remarks | Source
Programmer
USB Logic Analyser
GPIO Expander
Misclaneous

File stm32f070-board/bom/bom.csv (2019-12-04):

Id | Designator | Package | Quantity | Designation | Supplier and ref
1 | C12,C4,C6,C10 | C_0603_1608Metric_Pad1.05x0.95mm_HandSolder | 4 | 1uF
2 | U2 | TSSOP20_P0.65mm | 1 | STM32F070F6P6
3 | J3 | PinHeader_1x05_P1.00mm_Vertical | 1 | Conn_01x05_Male
4 | U1 | SOIC-16_3.9x9.9mm_P1.27mm | 1 | CH340G
5 | U3 | SOT-23 | 1 | MCP9700AT-ETT
6 | C1 | C_0603_1608Metric_Pad1.05x0.95mm_HandSolder | 1 | 4.7uF
7 | C2 | C_0603_1608Metric_Pad1.05x0.95mm_HandSolder | 1 | 10nF
8 | C3,C5 | C_0603_1608Metric_Pad1.05x0.95mm_HandSolder | 2 | 100nF
9 | C7,C9 | C_0603_1608Metric_Pad1.05x0.95mm_HandSolder | 2 | 22pF
10 | C8 | C_0603_1608Metric_Pad1.05x0.95mm_HandSolder | 1 | 100uF
11 | C11 | C_0603_1608Metric_Pad1.05x0.95mm_HandSolder | 1 | 0.1uF
12 | D1 | LED_VISHAY | 1 | PWR_LED
13 | D2 | LED_VISHAY | 1 | USR_LED2
14 | D3 | PLCC6 | 1 | LED_RGB
15 | D4 | LED_VISHAY | 1 | USR_LED1
16 | J1,J2 | usb | 2 | USB_B_Micro
17 | R1,R10 | R_0603_1608Metric_Pad1.05x0.95mm_HandSolder | 2 | 0R
18 | R2,R4,R8 | R_0603_1608Metric_Pad1.05x0.95mm_HandSolder | 3 | 750R
19 | R3,R9,R11,R12 | R_0603_1608Metric_Pad1.05x0.95mm_HandSolder | 4 | 10k
20 | R5 | R_0603_1608Metric_Pad1.05x0.95mm_HandSolder | 1 | 80R
21 | R6 | R_0603_1608Metric_Pad1.05x0.95mm_HandSolder | 1 | 60R
22 | R7 | R_0603_1608Metric_Pad1.05x0.95mm_HandSolder | 1 | 30R
23 | SW1 | SLIDE_SWITCH_3.6x9.0mm | 1 | SW_DPDT_x2
24 | SW2,SW3 | TACTILE_SWITCH_3.5X6.0mm | 2 | SW_Push
25 | U4 | Si705x_Footprint_P1.0mm | 1 | Si7055-A20
26 | VR1 | voltage-reg | 1 | LD39050PU33R
27 | Y1 | HC_49US-(AT49)_1 | 1 | 12MHz

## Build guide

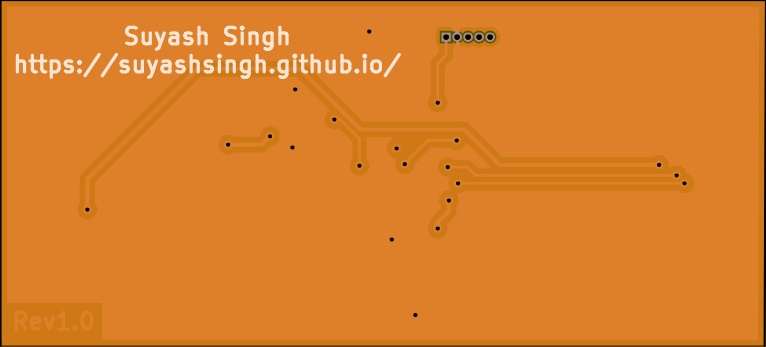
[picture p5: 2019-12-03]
stm32f070-board/manufacturing/fab-house-board-back.png

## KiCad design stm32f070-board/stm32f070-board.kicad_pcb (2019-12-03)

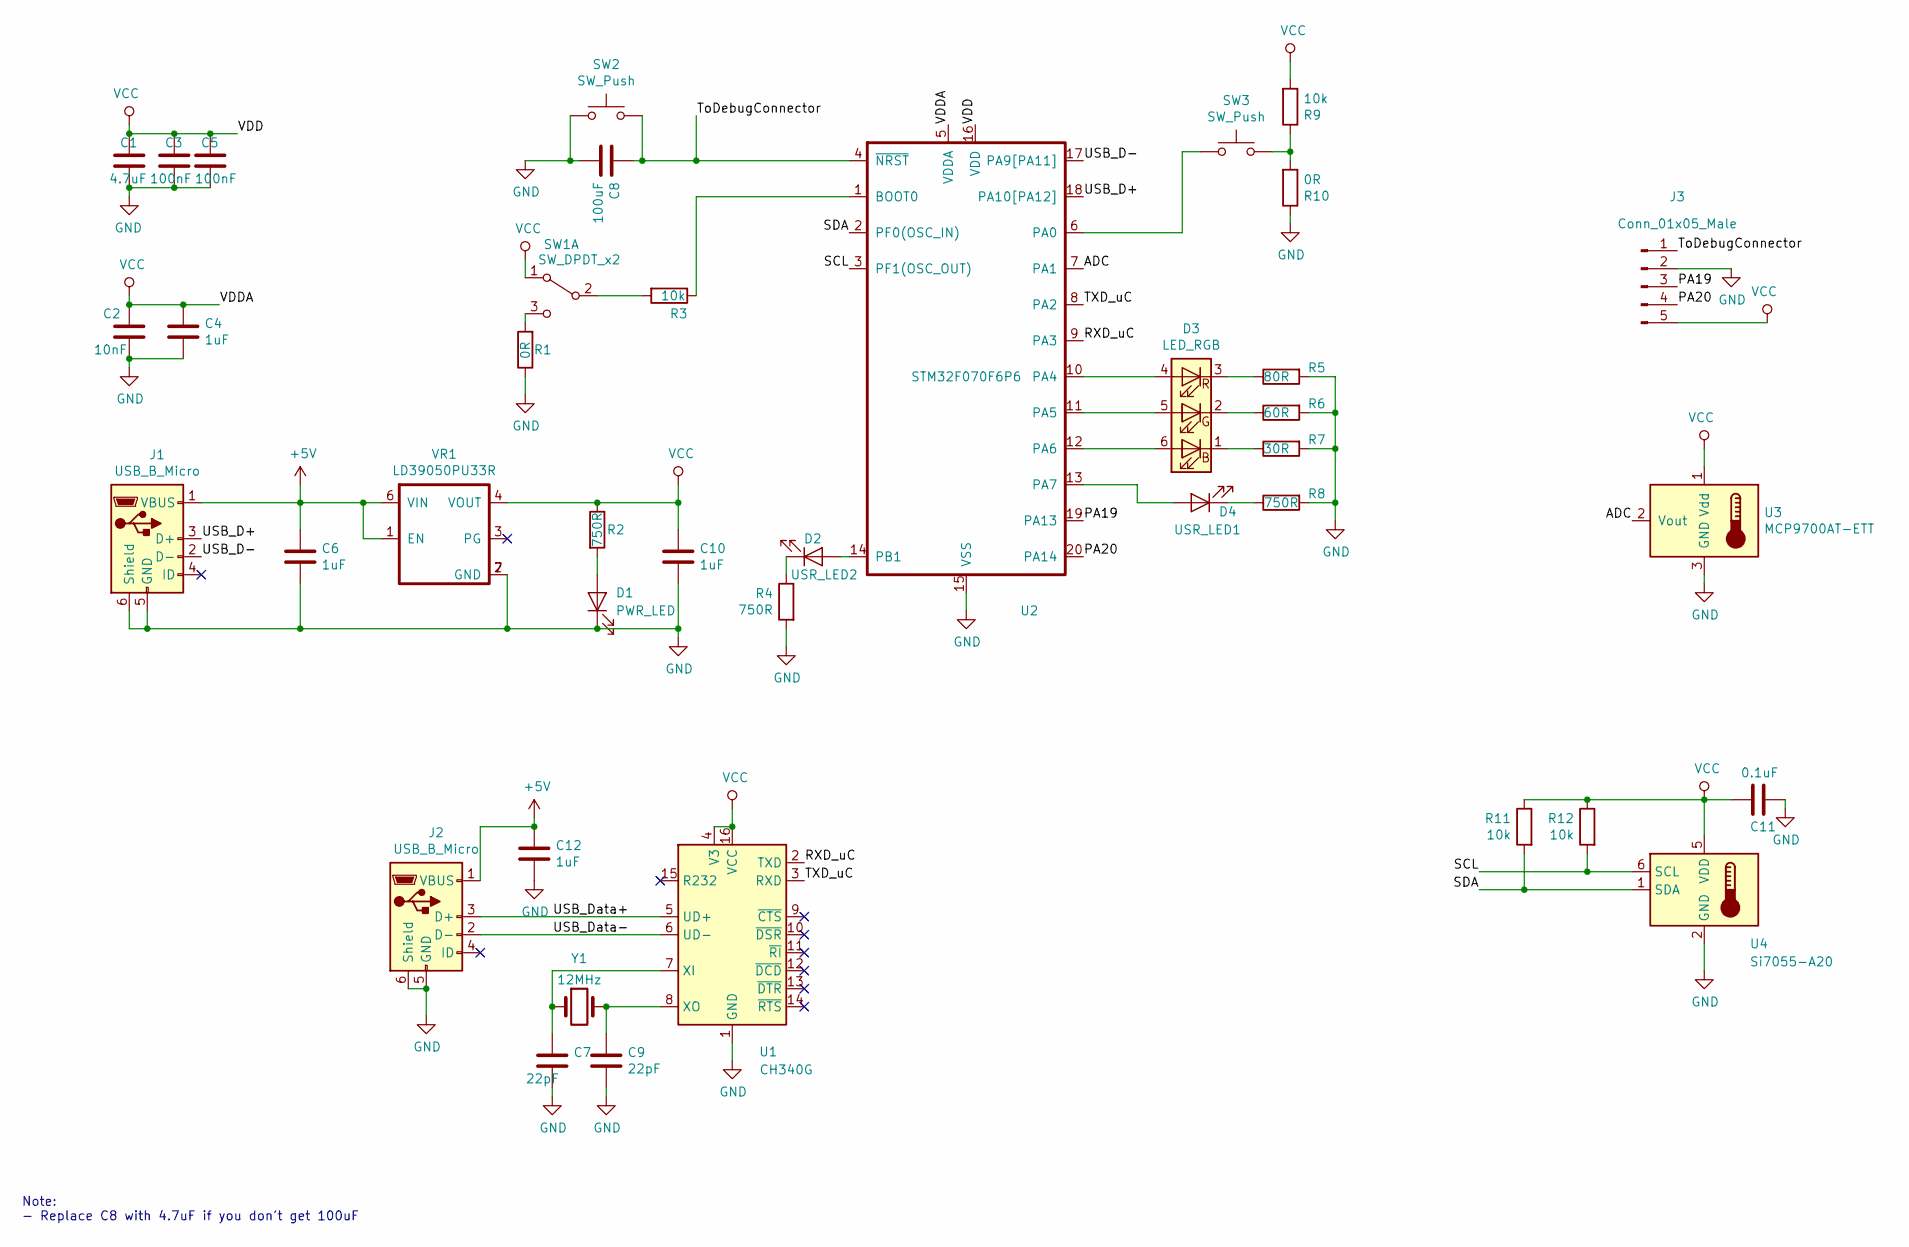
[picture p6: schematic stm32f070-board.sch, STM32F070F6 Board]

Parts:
C1: 4.7uF; C_0603_1608Metric_Pad1.05x0.95mm_HandSolder
C2: 10nF; C_0603_1608Metric_Pad1.05x0.95mm_HandSolder
C3, C5: 100nF; C_0603_1608Metric_Pad1.05x0.95mm_HandSolder
C4, C6, C10, C12: 1uF; C_0603_1608Metric_Pad1.05x0.95mm_HandSolder
C7, C9: 22pF; C_0603_1608Metric_Pad1.05x0.95mm_HandSolder
C8: 100uF; C_0603_1608Metric_Pad1.05x0.95mm_HandSolder
C11: 0.1uF; C_0603_1608Metric_Pad1.05x0.95mm_HandSolder
D1: PWR_LED; LED_VISHAY
D2: USR_LED2; LED_VISHAY
D3: LED_RGB; PLCC6
D4: USR_LED1; LED_VISHAY
J1, J2: USB_B_Micro; usb
J3: Conn_01x05_Male; PinHeader_1x05_P1.00mm_Vertical
R1, R10: 0R; R_0603_1608Metric_Pad1.05x0.95mm_HandSolder
R2, R4, R8: 750R; R_0603_1608Metric_Pad1.05x0.95mm_HandSolder
R3, R9, R11, R12: 10k; R_0603_1608Metric_Pad1.05x0.95mm_HandSolder
R5: 80R; R_0603_1608Metric_Pad1.05x0.95mm_HandSolder
R6: 60R; R_0603_1608Metric_Pad1.05x0.95mm_HandSolder
R7: 30R; R_0603_1608Metric_Pad1.05x0.95mm_HandSolder
SW1: SW_DPDT_x2; SLIDE_SWITCH_3.6x9.0mm
SW2, SW3: SW_Push; TACTILE_SWITCH_3.5X6.0mm
U1: CH340G; SOIC-16_3.9x9.9mm_P1.27mm
U2: STM32F070F6P6; TSSOP20_P0.65mm
U3: MCP9700AT-ETT; SOT-23
U4: Si7055-A20; Si705x_Footprint_P1.0mm
VR1: LD39050PU33R; voltage-reg
Y1: 12MHz; HC_49US-(AT49)_1

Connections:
+5V: C6.1, C12.1, J1.1 (VBUS), J2.1 (VBUS), VR1.1 (EN), VR1.6 (VIN)
/ADC: U2.7 (PA1), U3.2 (Vout)
/PA19: J3.3, U2.19 (PA13)
/PA20: J3.4, U2.20 (PA14)
/RXD_uC: U1.2 (TXD), U2.9 (PA3)
/SCL: R12.2, U2.3 (PF1(OSC_OUT)), U4.6 (SCL)
/SDA: R11.2, U2.2 (PF0(OSC_IN)), U4.1 (SDA)
/TXD_uC: U1.3 (RXD), U2.8 (PA2)
/ToDebugConnector: C8.1, J3.1, SW2.2, U2.4 (~NRST)
/USB_D+: J1.3 (D+), U2.18 (PA10[PA12])
/USB_D-: J1.2 (D-), U2.17 (PA9[PA11])
/USB_Data+: J2.3 (D+), U1.5 (UD+)
/USB_Data-: J2.2 (D-), U1.6 (UD-)
GND: C1.2, C2.2, C3.2, C4.2, C5.2, C6.2, C7.2, C8.2, C9.2, C10.2, C11.1, C12.2, D1.1 (K), J1.5 (GND), J1.6 (Shield), J2.5 (GND), J2.6 (Shield), J3.2, R1.1, R4.2, R5.2, R6.2, R7.2, R8.2, R10.1, SW2.1, U1.1 (GND), U2.15 (VSS), U3.3 (GND), U4.2 (GND), VR1.2 (GND), VR1.7 (GND)
unnamed: C7.1, U1.7 (XI), Y1.1
unnamed: C9.1, U1.8 (XO), Y1.2
unnamed: D1.2 (A), R2.2
unnamed: D2.1 (K), R4.1
unnamed: D2.2 (A), U2.14 (PB1)
unnamed: D3.1 (RK), R7.1
unnamed: D3.2 (GK), R6.1
unnamed: D3.3 (BK), R5.1
unnamed: D3.4 (BA), U2.10 (PA4)
unnamed: D3.5 (GA), U2.11 (PA5)
unnamed: D3.6 (RA), U2.12 (PA6)
unnamed: D4.1 (K), R8.1
unnamed: D4.2 (A), U2.13 (PA7)
unnamed: R1.2, SW1.3 (C)
unnamed: R3.1, U2.1 (BOOT0)
unnamed: R3.2, SW1.2 (B)
unnamed: R9.1, R10.2, SW3.2
unnamed: SW3.1, U2.6 (PA0)
VCC: C1.1, C2.1, C3.1, C4.1, C5.1, C10.1, C11.2, J3.5, R2.1, R9.2, R11.1, R12.1, SW1.1 (A), U1.4 (V3), U1.16 (VCC), U2.5 (VDDA), U2.16 (VDD), U3.1 (Vdd), U4.5 (VDD), VR1.4 (VOUT)

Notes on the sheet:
Note: - Replace C8 with 4.7uF if you don't get 100uF

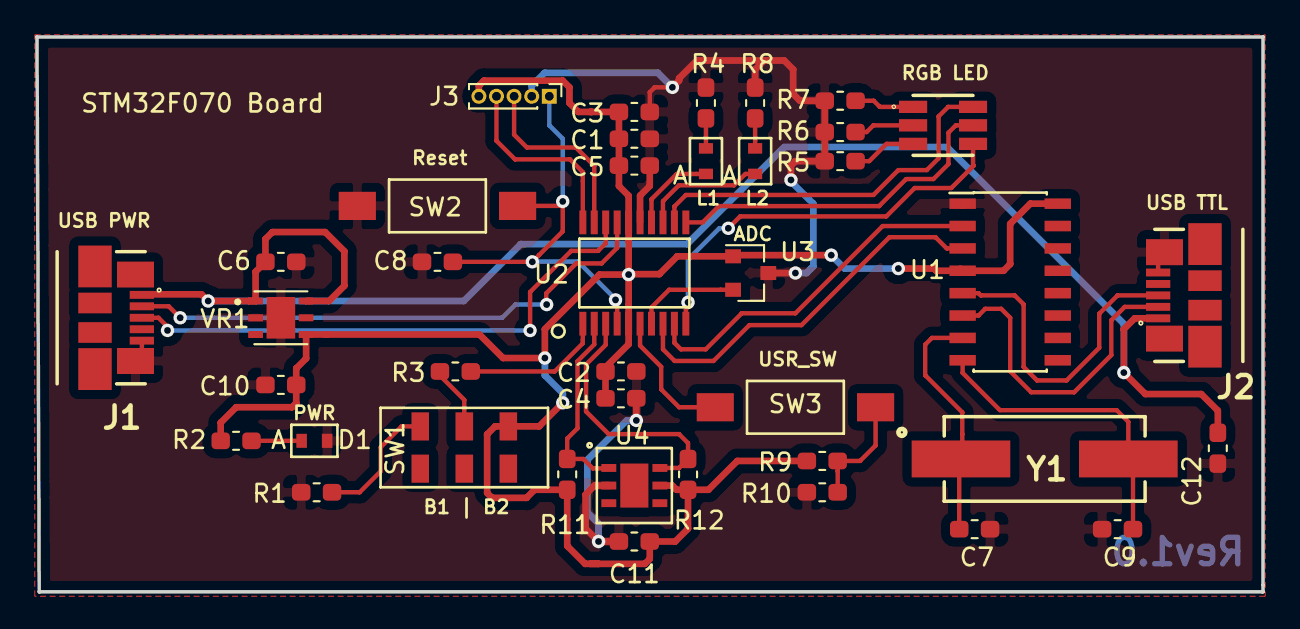
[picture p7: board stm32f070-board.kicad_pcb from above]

Board: 2 copper layers, 69.6 x 31.5 mm, 40 parts (0 on the bottom side), 33 nets.

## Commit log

2019-09-12 added initial project files and updated readme.
    [stm32f070-board.kicad_pcb, stm32f070-board.sch]
2019-09-12 created schematic symbol for 3V3 voltage regulator - LD3950
2019-09-12 drafted the 3v3 power supply section using LD3950
    [stm32f070-board.sch]
2019-09-12 created schematic symbol for STM32F070F6P6
2019-09-12 drafted schematic using STM32FO mcu symbol, added debug
    [stm32f070-board.sch]
2019-09-12 added connections for user switch and led
    [stm32f070-board.sch]
2019-09-12 created library for rgb led by modifying inbuild RGB led symbol and added rgb led to the main schematic.
    [stm32f070-board.sch]
2019-09-12 added temp sensors and ch340 to the schematic
    [stm32f070-board.sch]
2019-09-13 removed short in boot selector(added a 3way switch) and added zero ohm resistor in the user button.
    [stm32f070-board.sch]
2019-09-13 added values to the components
    [stm32f070-board.sch]
2019-09-13 added component values to missing components(cap parallel to the reset switch and user leds)
    [stm32f070-board.sch]
2019-09-13 replaced 10pin debug connector by 5 pin debug connector - removed redundant pins.
    [stm32f070-board.sch]
2019-09-13 annoted the schematic
    [stm32f070-board.sch]
2019-09-26 Added datasheet and product pages to the components
    [stm32f070-board.sch]
2019-09-26 Changed the user switch SW3 to toggle switch
    [stm32f070-board.sch]
2019-09-26 Moved all the notes to bottom left of the sheet.
    [stm32f070-board.sch]
2019-09-26 fixed broken link to product page for 0.1uF capacitor
    [stm32f070-board.sch]
2019-09-30 Added footprints to passive components
    [stm32f070-board.sch]
2019-09-30 added foot prints for caps and reistors
2019-09-30 added custom footprint for vishay led.
2019-09-30 added silkscreen layer for vishay led
2019-09-30 added led footprints
    [stm32f070-board.sch]
2019-09-30 removed old vishay led footprint from the schematic and made changes in the vishay led custom footprint
    [stm32f070-board.sch]
2019-10-01 Updated schematic
    [stm32f070-board.sch]
2019-10-04 changed incorrect pin numbers in tssop20 custom package
2019-10-04 added mechanical drawing from ch340g soic16 and updated footprints for stm32 in schematic
    [stm32f070-board.sch]
2019-10-04 changed the vendor of tactile user switch from robu to element14
    [stm32f070-board.sch]
2019-10-04 created footprint for tactile switch and updated it in the schematic
    [stm32f070-board.sch]
2019-10-04 created footprint for the slide switch and updated the same in schematic
    [stm32f070-board.sch]
2019-10-04 added footprint for rgb led from mouser.
2019-10-04 added footprint for rgb led in schematic
    [stm32f070-board.sch]
2019-10-04 added free hand drawn courtyard to rgb led and added 1st pin marker on f fab layer
2019-10-04 added footprint for voltage regulator and updated schematic
    [stm32f070-board.sch]
2019-10-04 added footprint for the crystal and updated it in the schematic
    [stm32f070-board.sch]
2019-10-04 added footprint for usb cable from mouser.in and added in schematic
    [stm32f070-board.sch]
2019-10-04 updated footprint for usb connector, created footprint for si705x sensor
    [stm32f070-board.sch]
2019-10-04 changed the footprint of si705x
    [stm32f070-board.kicad_pcb]
2019-10-04 saved the legacy footprint of voltage regulator into new .pretty footprint format and made minor changes to the footprint
    [stm32f070-board.sch]
2019-10-04 updated the note on the schematic page removed redundant comments
    [stm32f070-board.sch]
2019-10-04 changed positions of some refdes and values to make things look good
    [stm32f070-board.sch]
2019-10-05 exported netlist, imported the netlist in pcbnew and created bare board and added netlist import report
    [stm32f070-board.kicad_pcb]
2019-10-05 added drc rules fixed the pad near pad error for smd components with fine pitch by setting their pad clearance to 0.004"
    [stm32f070-board.kicad_pcb]
2019-10-05 organized components in layout in section wise manner
    [stm32f070-board.kicad_pcb]
2019-10-05 first iteration of routing the board -- approx 8 gnd airwires are unrouted evenafter pour
    [stm32f070-board.kicad_pcb]
2019-12-03 moved stale master branch to archive directory
    [stm32f070-board.kicad_pcb, stm32f070-board.sch]
2019-12-03 Merged branches: single-side-layout and master
    [stm32f070-board-B.Cu.gbl, stm32f070-board-B.Mask.gbs, stm32f070-board-B.Paste.gbp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]
2019-12-03 updated readme with images of the board
2019-12-03 updated readme
    added board bring up checklist and timeline
2019-12-04 added basic bom file
    [bom.csv]
2019-12-17 Added new bom file in open office format
    [stm32f070-board_bom.ods]
2019-12-17 added pictures of the fabricated board, updated timeline
2019-12-17 updated time line in readme - updated bom
    [stm32f070-board_bom.ods]
